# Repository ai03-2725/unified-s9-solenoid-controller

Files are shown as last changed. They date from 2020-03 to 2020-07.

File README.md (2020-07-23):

## **Unified-S9 9V Solenoid Driver**

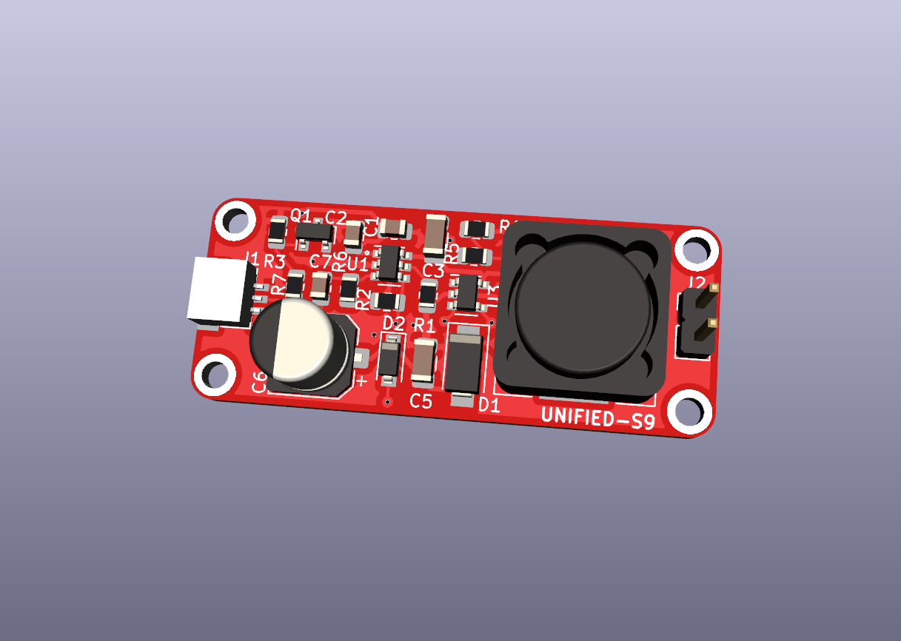
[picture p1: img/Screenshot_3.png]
Solenoid Driver


**Note:** Prototype not confirmed functional. Please modify to function before producing.

Based on [Xwhatit's work](https://geekhack.org/index.php?topic=58192), modified to work natively through QMK's haptic feedback/solenoid implementation.  
Open-source and extremely compacted to be easily implementable by custom keyboard designers.  

All credits for the original circuitry goes to Xwhatsit (source viewable [here](https://github.com/BASLQC/xwhatits-capsense-controller)).  
Many credits to Gondolindrim and Wilba for assistance along the way.

For the rest of the unified daughterboard series, see [here](https://github.com/ai03-2725/Unified-Daughterboard).

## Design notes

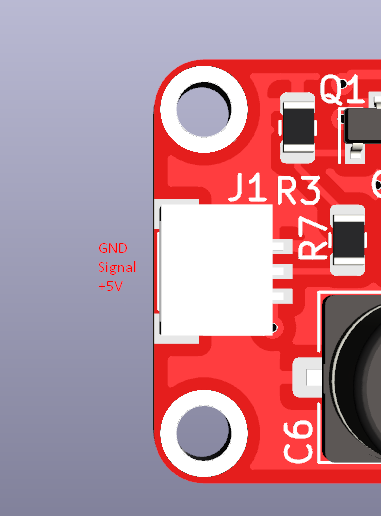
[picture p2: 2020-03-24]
Designer Resources/Pinout.png

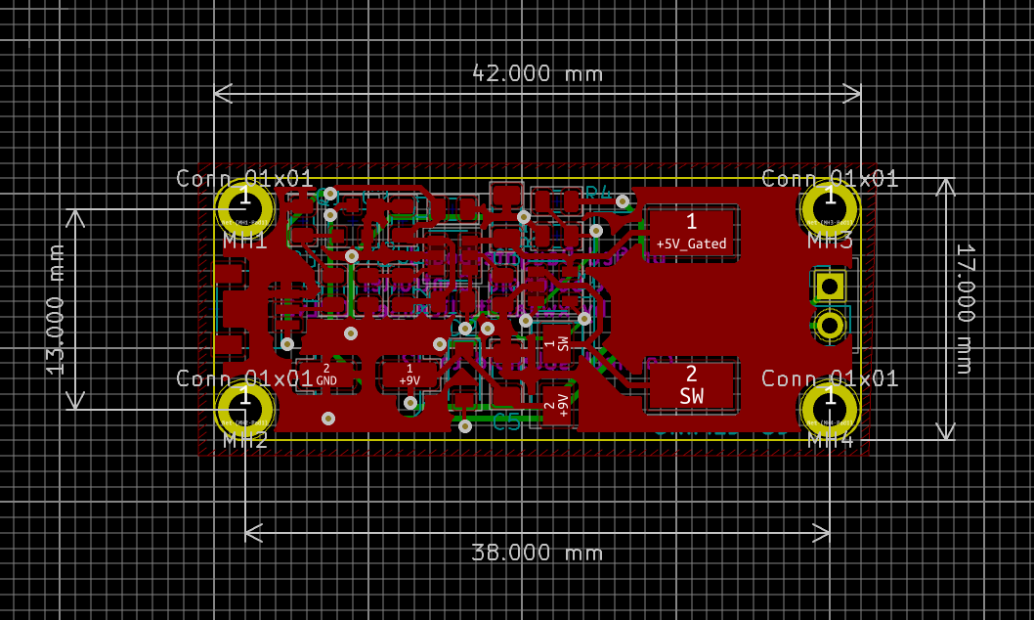
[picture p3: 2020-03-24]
Designer Resources/Dimens.png

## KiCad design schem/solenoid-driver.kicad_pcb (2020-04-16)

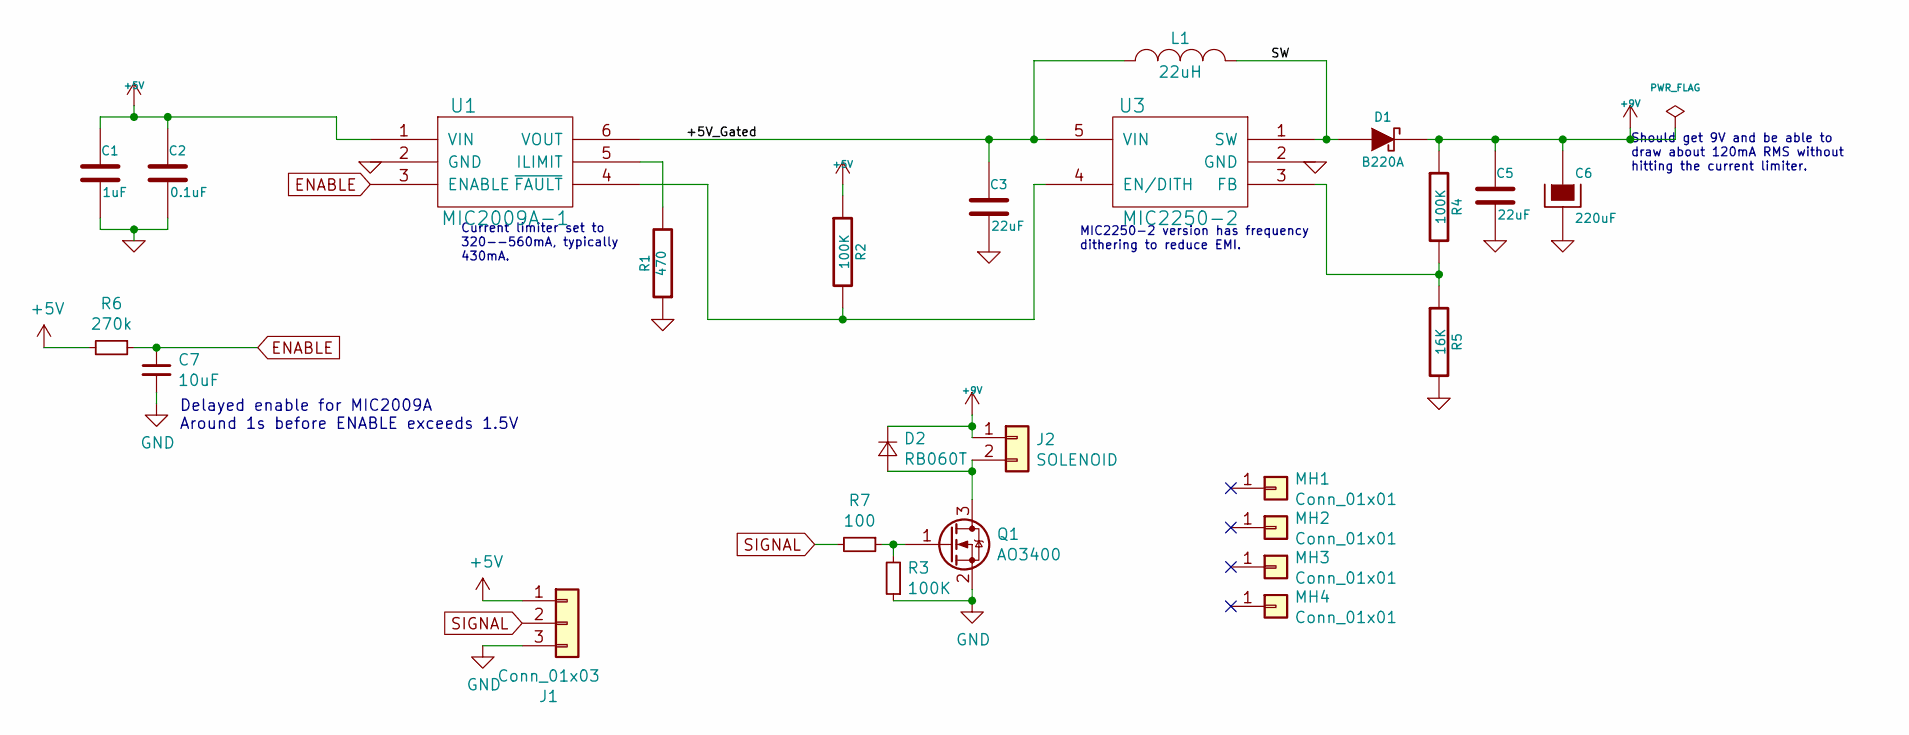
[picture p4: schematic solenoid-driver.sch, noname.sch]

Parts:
C1: 1uF; C_0805_2012Metric
C2: 0.1uF; C_0805_2012Metric
C3, C5: 22uF; C_1206_3216Metric
C6: 220uF; CP_Elec_6.3x7.7
C7: 10uF; C_0805_2012Metric
D1: B220A; D_SMA
D2: RB060T; D_SOD-123
J1: Conn_01x03; JST-SR-3
J2: SOLENOID; PinHeader_1x02_P2.54mm_Vertical
L1: 22uH; L_12x12mm_H6mm
MH1, MH2, MH3, MH4: Conn_01x01; Generic-Mounthole
Q1: AO3400; SOT-23
R1: 470; R_0805_2012Metric
R2, R3, R4: 100K; R_0805_2012Metric
R5: 16K; R_0805_2012Metric
R6: 270k; R_0805_2012Metric
R7: 100; R_0805_2012Metric
U1: MIC2009A-1; SOT-23-6
U3: MIC2250-2; SOT-23-5

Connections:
+5V: C1.1, C2.1, J1.1, R2.1, R6.2, U1.1 (VIN)
+9V: C5.1, C6.1, D1.2 (K), D2.1 (K), J2.1, R4.1
/+5V_Gated: C3.1, L1.1, U1.6 (VOUT), U3.5 (VIN)
/SW: D1.1 (A), L1.2, U3.1 (SW)
ENABLE: C7.1, R6.1, U1.3 (ENABLE)
GND: C1.2, C2.2, C3.2, C5.2, C6.2, C7.2, J1.3, Q1.2 (S), R1.1, R3.1, R5.2, U1.2 (GND), U3.2 (GND)
unnamed: D2.2 (A), J2.2, Q1.3 (D)
unnamed: Q1.1 (G), R3.2, R7.1
unnamed: R1.2, U1.5 (ILIMIT)
unnamed: R2.2, U1.4 (~FAULT), U3.4 (EN/DITH)
unnamed: R4.2, R5.1, U3.3 (FB)
SIGNAL: J1.2, R7.2

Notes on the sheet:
Should get 9V and be able to draw about 120mA RMS without hitting the current limiter.
Current limiter set to 320--560mA, typically 430mA.
MIC2250-2 version has frequency dithering to reduce EMI.
Delayed enable for MIC2009A Around 1s before ENABLE exceeds 1.5V

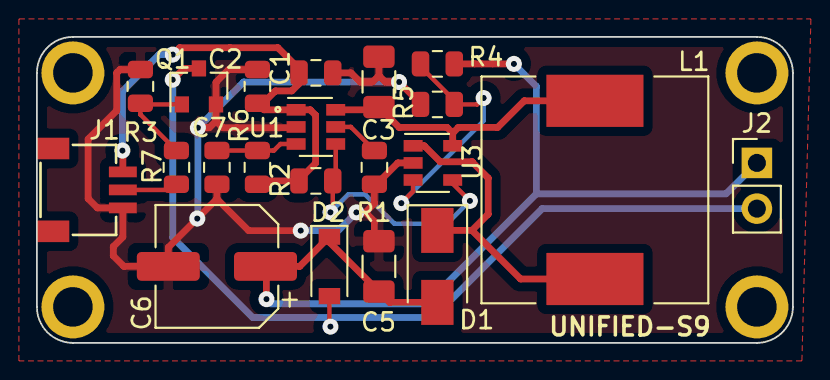
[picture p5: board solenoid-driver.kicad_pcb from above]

Board: 2 copper layers, 42.0 x 17.0 mm, 25 parts (0 on the bottom side), 12 nets.

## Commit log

2020-03-24 Remove all but the solenoid controller files
    [amkey-usb.kicad_pcb, amkey-usb.sch, beamspring-usb.kicad_pcb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]
2020-03-24 Update to KiCad 5.1.4 openable format
    [solenoid-driver-2020-03-24-10-46-05.sch]
2020-03-24 Tune up schema
    [solenoid-driver.sch]
2020-03-24 Route the PCB
    [solenoid-driver.kicad_pcb, solenoid-driver.sch]
2020-03-24 Finalize PCB
    [solenoid-driver.kicad_pcb, solenoid-driver.sch]
2020-03-24 Add barebones documentation
    [solenoid-driver.kicad_pcb]
2020-03-24 Add gerbers
    [solenoid-driver-B_Cu.gbl, solenoid-driver-B_Mask.gbs, solenoid-driver-B_Paste.gbp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]
2020-03-31 Fix pinout and regenerate gerber
    [solenoid-driver-B_Cu.gbl, solenoid-driver-B_Mask.gbs, solenoid-driver-B_Paste.gbp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]
2020-04-16 Remove an unnecessary via
    [solenoid-driver-B_Cu.gbl, solenoid-driver-B_Mask.gbs, solenoid-driver-B_Paste.gbp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]

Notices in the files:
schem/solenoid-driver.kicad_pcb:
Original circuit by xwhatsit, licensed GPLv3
